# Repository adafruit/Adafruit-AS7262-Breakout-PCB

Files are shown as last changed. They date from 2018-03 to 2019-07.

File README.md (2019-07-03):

## Adafruit AS7262 Channel Visible Light / Color Sensor Breakout PCB

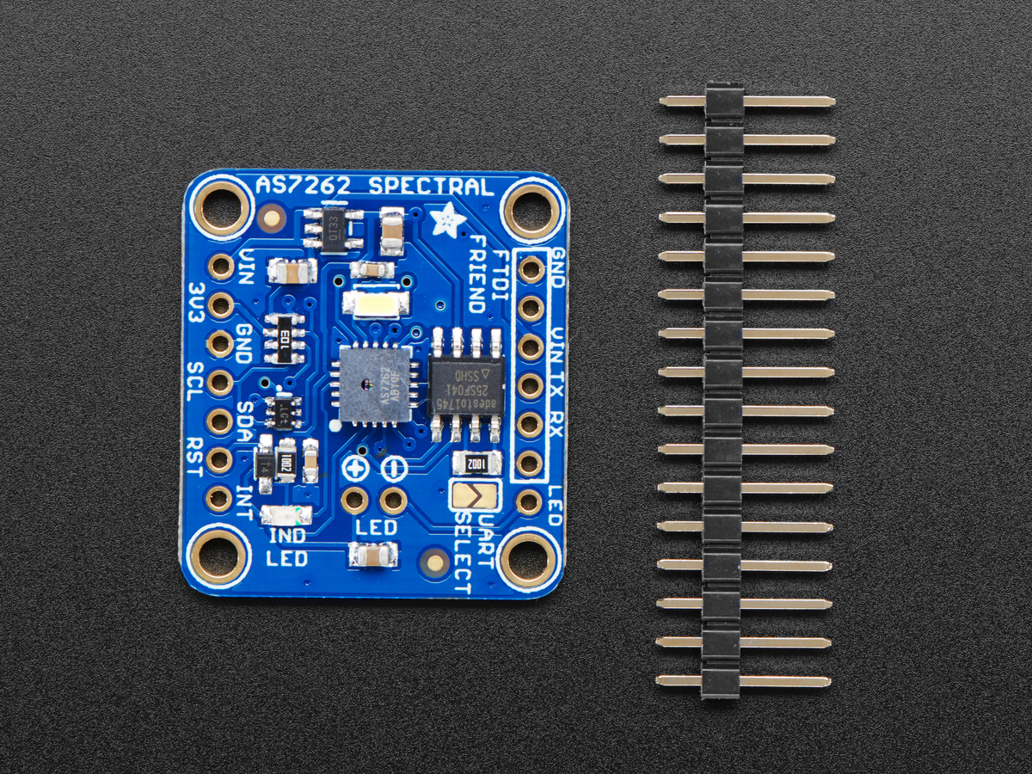
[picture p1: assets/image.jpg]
<a href="http://www.adafruit.com/products/3779"><br/>
Click here to purchase one from the Adafruit shop</a>

PCB files for AS7262 breakout. Format is EagleCAD schematic and board layout

For more details, check out the product page at
* https://www.adafruit.com/products/3779

### Description

Detect trees of green, and red roses too with the new Adafruit AS7262 6-Channel Visible Light / Color Sensor Breakout. This sensor from AMS has 6 integrated visible light sensing channels for red, orange, yellow, green, blue, and violet. These channels can be read via the I2C bus as either raw 16-bit values or calibrated floating-point values. There is also an on-board temperature sensor that can be used to read the temperature of the chip, and a powerful LED flash to reflect light off objects for better color detection.

The 6 channels on the AS7262 are realized by silicon interference filters at 450nm, 500nm, 550nm, 570nm, 600nm, and 650nm. This breakout uses the I2C interface on the chip by default, but a UART interface that accepts AT commands is also selectable.

We've placed the sensor on a PCB for you and included an SPI flash chip pre-programmed with the device firmware, a 3.3V regulator, I2C level shifting, and the recommended LED flash. Both the I2C and UART interfaces are broken out, making this breakout an excellent all-in-one solution for all your color-sensing needs. The pinout for the UART interface is plug-and-play compatible with the Adafruit FTDI Friend.

### License

Adafruit invests time and resources providing this open source design, please support Adafruit and open-source hardware by purchasing products from [Adafruit](https://www.adafruit.com)!

Designed by Limor Fried/Ladyada for Adafruit Industries.

Creative Commons Attribution/Share-Alike, all text above must be included in any redistribution. See license.txt for additional details.

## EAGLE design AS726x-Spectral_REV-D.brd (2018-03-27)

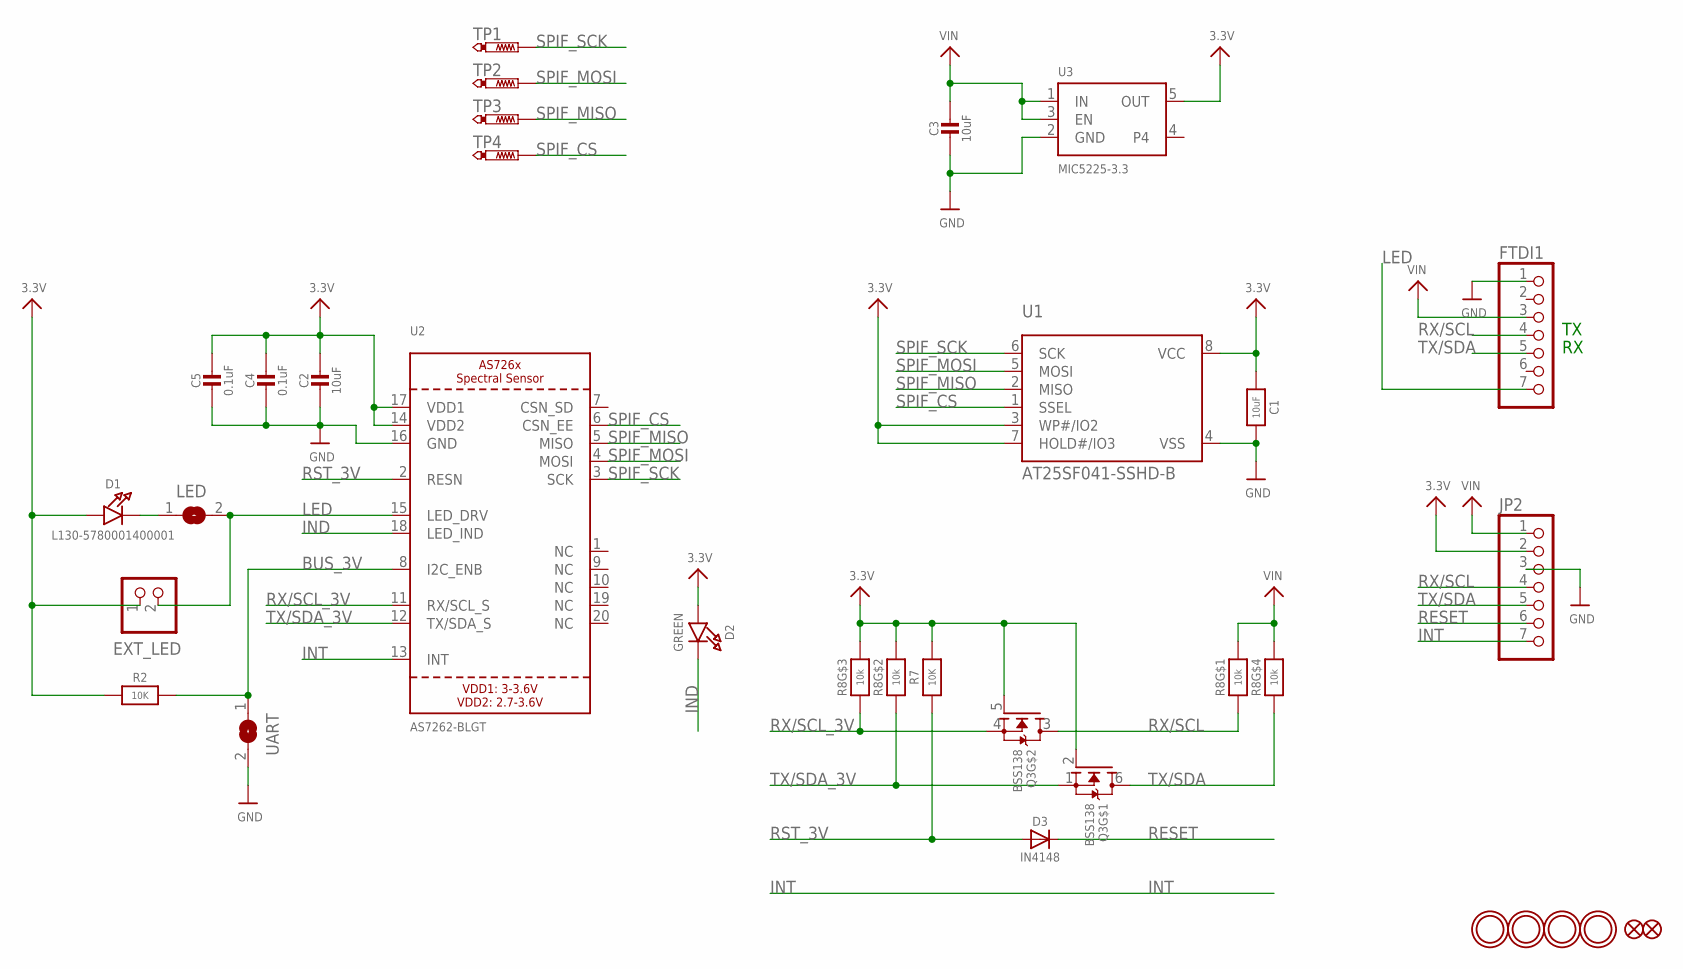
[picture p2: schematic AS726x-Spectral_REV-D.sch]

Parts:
C1, C2, C3: 10uF; 0805-NO
C4, C5: 0.1uF; 0603-NO
D1: L130-5780001400001; EVERLIGHT_45-21
D2: GREEN; CHIPLED_0805_NOOUTLINE
D3: IN4148; SOD-323
EXT_LED: HEADER-1X2ROUND; 1X02_ROUND
FID2, FID3: FIDUCIAL_1MM
FTDI1: HEADER-1X7ROUND; 1X07_ROUND
JP2: HEADER-1X7ROUND; 1X07_ROUND
LED: SOLDERJUMPERCLOSED; SOLDERJUMPER_CLOSEDWIRE
Q3: BSS138; SOT363
R2: 10K; 0805-NO
R7: 10K; 0603-NO
R8: 10k; RESPACK_4X0603_NO
TP1, TP2, TP3, TP4: PTR1TP15R; TP15R
U1: AT25SF041-SSHD-B; SOIC8_150MIL
U2: AS7262-BLGT; AS726X_LGA20
U3: MIC5225-3.3; SOT23-5
U$2, U$3, U$22, U$23: MOUNTINGHOLE2.5; MOUNTINGHOLE_2.5_PLATED
UART: SOLDERJUMPER; SOLDERJUMPER_ARROW_NOPASTE

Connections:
3.3V: C1.1, C2.1, C4.1, C5.1, D1.A, D2.A, EXT_LED.1, JP2.2, Q3.2 (G), Q3.5 (G), R2.1, R7.2, R8.6 (2), R8.7 (2), U1.3 (WP#/IO2), U1.7 (HOLD#/IO3), U1.8 (VCC), U2.14 (VDD2), U2.17 (VDD1), U3.5 (OUT)
BUS_3V: R2.2, U2.8 (I2C_ENB), UART.1
GND: C1.2, C2.2, C3.2, C4.2, C5.2, FTDI1.1, JP2.3, U1.4 (VSS), U2.16 (GND), U3.2 (GND), UART.2
IND: D2.C, U2.18 (LED_IND)
INT: JP2.7, U2.13 (INT)
LED: EXT_LED.2, FTDI1.7, LED.2, U2.15 (LED_DRV)
unnamed: D1.K (C), LED.1
RESET: D3.C, JP2.6
RST_3V: D3.A, R7.1, U2.2 (RESN)
RX/SCL: FTDI1.4, JP2.4, Q3.3 (D), R8.1
RX/SCL_3V: Q3.4 (S), R8.3 (1), U2.11 (RX/SCL_S)
SPIF_CS: TP4.TP, U1.1 (SSEL), U2.6 (CSN_EE)
SPIF_MISO: TP3.TP, U1.2 (MISO), U2.5 (MISO)
SPIF_MOSI: TP2.TP, U1.5 (MOSI), U2.4 (MOSI)
SPIF_SCK: TP1.TP, U1.6 (SCK), U2.3 (SCK)
TX/SDA: FTDI1.5, JP2.5, Q3.6 (D), R8.4 (1)
TX/SDA_3V: Q3.1 (S), R8.2 (1), U2.12 (TX/SDA_S)
VIN: C3.1, FTDI1.3, JP2.1, R8.5 (2), R8.8 (2), U3.1 (IN), U3.3 (EN)

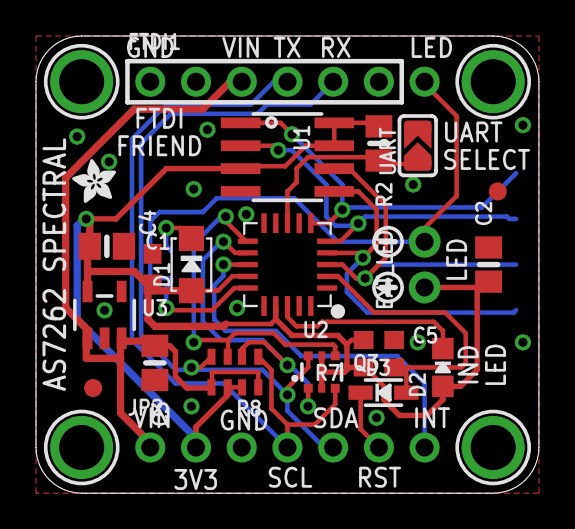
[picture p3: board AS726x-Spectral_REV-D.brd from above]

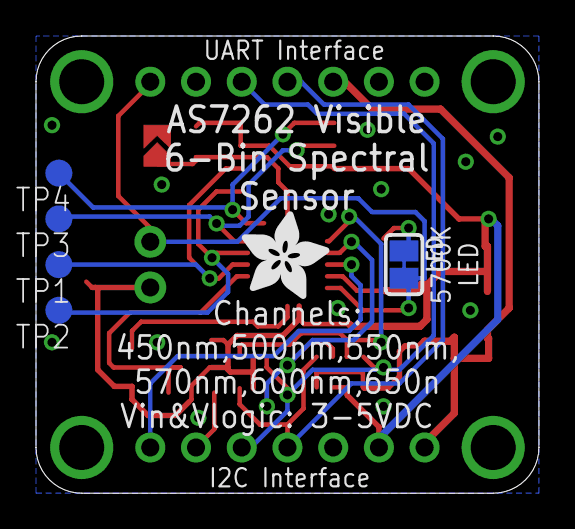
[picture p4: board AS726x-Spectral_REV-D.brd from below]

Board: 2 copper layers, 27.9 x 25.4 mm, 34 parts (6 on the bottom side), 18 nets.

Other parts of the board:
U$9: ADAFRUIT_5MM
U$21: ADAFRUIT_2.5MM
U$25: SYMBOL_PLUS
U$26: SYMBOL_MINUS

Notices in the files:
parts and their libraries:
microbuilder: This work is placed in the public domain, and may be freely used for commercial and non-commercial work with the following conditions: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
